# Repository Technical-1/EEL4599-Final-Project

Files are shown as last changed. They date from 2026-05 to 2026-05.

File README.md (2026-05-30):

# EEL4599 Final Project — Wireless Sensor Network

A multi-node wireless sensor network built around XBee/802.15.4 radios. Battery-powered sensor nodes measure temperature and light, transmit readings over the air as binary XBee API frames, and a WiFi-connected coordinator forwards those readings to the cloud (ThingSpeak) for logging and display.

This was a two-person final project for EEL4599. My focus was the **base-station coordinator** — the WiFi/cloud side that receives radio data and pushes it to ThingSpeak — alongside the shared XBee API frame work.

## System at a glance

```
[Temp Node]  --\
                 >--(XBee 802.15.4 RF)-->  [Coordinator] --(WiFi/HTTP)--> [ThingSpeak cloud]
[Light Node] --/                            + OLED status
```

## Features

- **Portable XBee API protocol layer** — a single C header (`xbee_api.h`) builds and parses XBee API frames (AT commands, transmit requests, receive packets) with checksum generation/verification, reused unchanged across Raspberry Pi Pico and Arduino targets.
- **Temperature node** — Raspberry Pi Pico reads a thermistor via the 12-bit ADC, converts resistance to temperature with the B-parameter (Steinhart–Hart) equation, and oversamples across a fixed interval to reduce noise before transmitting.
- **Light node** — Arduino-based node that reads a luminosity sensor and transmits lux readings over the same XBee frame format.
- **WiFi coordinator** — receives XBee data over UART and uploads it to ThingSpeak over HTTP; an SSD1306 OLED shows connection status and the assigned IP.
- **Host-side tools** — small Python and C utilities for sniffing and decoding XBee API frames during bring-up and debugging.

## Tech Stack

- **Languages**: C (embedded), CircuitPython / MicroPython, Arduino C++, Python (host tools)
- **Microcontrollers**: Raspberry Pi Pico (RP2040), Arduino, ESP8266, Adafruit Feather + ESP32 (AirLift) co-processor
- **Radio**: Digi XBee (802.15.4 / Zigbee) in API mode
- **Cloud**: ThingSpeak (HTTP REST ingest)
- **Build**: Pico SDK (CMake) for the Pico targets; Arduino IDE for the Arduino/ESP targets
- **Hardware design**: KiCad schematics for each node

## Project Structure

Each network component lives in its own directory:

```
EEL4599-Final-Project/
├── BaseStation/        # ESP8266 base station: WiFi connect + OLED status
├── FeatherWingFiles/   # CircuitPython coordinator that forwards XBee data to ThingSpeak
├── TempNode/           # Pico thermistor node (C, Pico SDK)
├── LightNode/          # Arduino luminosity node
├── XBeeAPI/            # XBee API frame library (xbee_api.h) + reference firmware
├── SerialReader/       # Host-side C tool that decodes XBee frames from a serial port
├── Diagrams/           # KiCad schematics and the data-flow diagram
├── ReceiveData.py      # Host-side digi-xbee receive tool
└── .portfolio/         # Project documentation
```

The three sensor/reference firmwares share one protocol implementation: `TempNode/xbee_api.h` and `LightNode/xbee_api.h` are **symlinks** to `XBeeAPI/xbee_api.h`, so there is a single source of truth for the frame format.

## Getting Started

### Prerequisites

- A pair (or more) of Digi XBee radios configured in **API mode**, one as coordinator
- Target boards: Raspberry Pi Pico and/or Arduino-class board for sensor nodes; an ESP8266/Feather for the coordinator
- [Pico SDK](https://github.com/raspberrypi/pico-sdk) + CMake (Pico targets) and/or the Arduino IDE
- Python 3 with the `digi-xbee` library for the host receive tool

### Build a Pico sensor node

```bash
# from the TempNode/ (or XBeeAPI/) directory
mkdir build && cd build
cmake ..
make
# flash the resulting .uf2 to the Pico
```

### Flash an Arduino node / coordinator

Open `LightNode/LightNode.ino` or `BaseStation/BaseStation.ino` in the Arduino IDE and upload to the board.

For the ESP8266 base station, create `BaseStation/WiFiCredentials.h` (git-ignored):

```c
const char* ssid = "your-ssid";
const char* pwd  = "your-password";
```

### Run the host receive tool

```bash
pip install digi-xbee
python ReceiveData.py   # edit PORT/BAUD_RATE to match your XBee
```

## License

Unlicensed (academic project).

## Authors

Jacob Kanfer — [GitHub](https://github.com/Technical-1) — and project partner. Two-person final project for EEL4599.

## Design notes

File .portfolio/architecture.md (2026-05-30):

# Architecture

## System Diagram

```mermaid
flowchart LR
    subgraph Sensor Nodes
        TN["Temp Node<br/>(RP2040 / Pico, C)<br/>thermistor + ADC"]
        LN["Light Node<br/>(Arduino)<br/>luminosity sensor"]
    end

    subgraph Shared
        API["xbee_api.h<br/>API-frame encode/decode<br/>+ checksum"]
    end

    TN -- includes --> API
    LN -- includes --> API

    TN -- "0x10 Transmit Request<br/>(2-byte payload)" --> RF(("XBee RF<br/>802.15.4"))
    LN -- "0x10 Transmit Request" --> RF

    RF -- "0x90 Receive Packet" --> CO["Coordinator<br/>(ESP8266 / Feather+ESP32)<br/>UART in"]
    CO -- "HTTP GET /update" --> TS["ThingSpeak<br/>cloud channel"]
    CO -- status --> OLED["SSD1306 OLED"]

    RF -. debug .-> HOST["Host tools<br/>ReceiveData.py /<br/>SerialReader.c"]
```

## Component Descriptions

### XBee API frame library
- **Purpose**: Encode and decode XBee API-mode frames so firmware never hand-assembles raw byte buffers.
- **Location**: `XBeeAPI/xbee_api.h` (symlinked from `TempNode/xbee_api.h` and `LightNode/xbee_api.h`, so all nodes share one copy)
- **Key responsibilities**: build AT command frames (`0x08`), transmit-request frames (`0x10`), and parse receive packets (`0x90`); compute and verify the XBee checksum; grow the frame buffer with `realloc` as needed. All UART I/O is delegated to two functions the host firmware must provide: `xbee_api_uart_write()` and `xbee_api_uart_getchar()`.

### Temperature node
- **Purpose**: Measure ambient temperature and broadcast it.
- **Location**: `TempNode/main.c`
- **Key responsibilities**: initialize UART + ADC on the Pico; oversample the thermistor across a fixed time window and average; convert ADC counts → resistance (voltage-divider) → temperature (B-parameter equation) → Fahrenheit; encode the reading as a fixed-point `int16` (°F × 10) and transmit it.

### Light node
- **Purpose**: Measure luminosity and broadcast it.
- **Location**: `LightNode/LightNode.ino`
- **Key responsibilities**: read the light sensor and transmit a 2-byte reading using the same XBee frame format, with the Arduino `Serial` port wired in as the API library's UART backend.

### Coordinator / base station
- **Purpose**: Receive sensor data over the air and forward it to the cloud.
- **Location**: `BaseStation/BaseStation.ino` (ESP8266 + OLED) and `FeatherWingFiles/code.py` (CircuitPython on Feather + ESP32 AirLift)
- **Key responsibilities**: connect to WiFi; read XBee frames over UART; issue an HTTP GET to the ThingSpeak `/update` endpoint with the reading in a field parameter; surface connection state and IP on the SSD1306 OLED.

### Host-side decoding tools
- **Purpose**: Bring-up and debugging without a microcontroller in the loop.
- **Location**: `ReceiveData.py` (digi-xbee library), `SerialReader/SerialReader.c` (raw serial parse), `XBeeAPI/xbee_api_receive.py`
- **Key responsibilities**: read frames from a serial port and print the decoded payload, so frame formatting and sensor math can be verified on a laptop.

## Data Flow

1. A sensor node samples its sensor (thermistor ADC, or light sensor).
2. The raw reading is converted to a physical value and packed into a 2-byte fixed-point payload.
3. The payload is wrapped in an XBee `0x10` transmit-request frame (with destination address and checksum) and written to the radio over UART.
4. The XBee mesh delivers the frame to the coordinator, which receives it as a `0x90` packet and extracts the payload.
5. The coordinator builds a ThingSpeak `/update` URL with the reading and issues an HTTP GET over WiFi; the OLED reflects status.

## External Integrations

| Service | Purpose | Notes |
|---|---|---|
| ThingSpeak  | Cloud logging / charting of data | HTTP GET to `/update` with an API key; one field per metric. |
| XBee radios | The RF transport itself | API mode (not transparent/AT mode) so payloads carry addressing + framing. |

## Key Architectural Decisions

### One protocol library, many MCUs
- **Context**: The temperature node (Pico, C/Pico SDK) and the light node (Arduino C++) run on different toolchains and have completely different UART APIs, but both must speak identical XBee frames.
- **Decision**: Put all framing logic in a header (`xbee_api.h`) that calls two externally-defined I/O functions, and let each firmware define those functions against its own UART.
- **Rationale**: Avoids forking the protocol code per board and guarantees the temp and light nodes can't drift into incompatible frame formats. The alternative — duplicating frame code in each `.ino`/`.c` — would have doubled the surface area for checksum/offset bugs.

### XBee API mode over transparent mode
- **Context**: Multiple sensor nodes report to one coordinator, which needs to know *who* sent each reading.
- **Decision**: Run the radios in API mode and parse `0x90` receive packets, which include the sender's 64-bit address, rather than transparent serial passthrough.
- **Rationale**: Transparent mode would have merged all nodes into one undifferentiated byte stream. API mode preserves per-node addressing and delivery status for free.

### Fixed-point payloads instead of strings
- **Context**: RF airtime and MCU memory are limited, and floats are awkward to transmit reliably.
- **Decision**: Encode each reading as a 2-byte `int16` scaled by 10 (e.g. 73.4 °F → `734`) and reconstruct on the receiver.
- **Rationale**: Keeps payloads to 2 bytes with predictable framing and no parsing ambiguity, versus sending variable-length ASCII like `"73.4F"`.

### Shared protocol library via symlinks
- **Context**: Three firmwares (the two Pico C targets and the Arduino node) each need the XBee frame code, but duplicating the header invites the copies to drift apart.
- **Decision**: Keep one real `XBeeAPI/xbee_api.h` and point `TempNode/xbee_api.h` and `LightNode/xbee_api.h` at it with symlinks, so each firmware still `#include "xbee_api.h"` locally but compiles the same bytes.
- **Rationale**: Guarantees one source of truth for the wire format across boards with different build systems (CMake vs Arduino IDE), without a build step to copy files around. The alternative — committing three independent copies — is exactly how the temp and light nodes briefly diverged during parallel development before being unified.

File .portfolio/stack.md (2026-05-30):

# Tech Stack

## Core Technologies

| Category | Technology | Why this choice |
|---|---|---|
| Sensor-node lang| C (Pico SDK) | Direct register/ADC/UART control on the RP2040 with predictable timing. |
| Sensor-node lang| Arduino C++ | Fast bring-up for the light node on Arduino-class hardware. |
| Coordinator lang| CircuitPython / MicroPython | High-level WiFi + HTTP on the Feather/ESP32 without a full native toolchain.|
| Coordinator lang| Arduino C++ (ESP8266 core) | OLED + WiFi on the ESP8266 base station. |
| RF transport | Digi XBee (802.15.4 / Zigbee) | API mode gives per-node addressing and delivery status. |
| Cloud | ThingSpeak | Free, HTTP-GET ingest and built-in charts — minimal coordinator code. |

## Sensor nodes

- **Temperature**: Raspberry Pi Pico (RP2040), thermistor on a voltage divider into the 12-bit ADC, B-parameter temperature model, oversampled and averaged in `TempNode/main.c`.
- **Light**: Arduino board reading a luminosity sensor, transmitting via `LightNode/LightNode.ino`.
- **Shared protocol**: `xbee_api.h` — hardware-agnostic XBee API frame encode/decode.

## Coordinator / base station

- **Boards**: ESP8266 (`BaseStation.ino`) and Adafruit Feather + ESP32 AirLift co-processor (`FeatherWingFiles/code.py`).
- **Display**: SSD1306 128×32 OLED over I²C (`Adafruit_SSD1306` + `Adafruit_GFX`).
- **Networking**: ESP8266 `WiFi`/`HTTPClient`, or `adafruit_esp32spi` + `adafruit_requests` on the Feather.

## Build & Tooling

- **Pico targets**: CMake + Pico SDK (`CMakeLists.txt`, `pico_sdk_import.cmake`), producing a `.uf2` to flash.
- **Arduino/ESP targets**: Arduino IDE / ESP8266 Arduino core.
- **Hardware design**: KiCad schematics for the base, temp, and light nodes (`Diagrams/schematic/`); data-flow diagram in draw.io.
- **Secrets**: WiFi credentials and the ThingSpeak API key are kept out of the repo (git-ignored `WiFiCredentials.h` / `secrets`).

## Key Dependencies

| Package | Purpose |
|---|---|
| `pico/stdlib`, `hardware/adc`, `hardware/uart` | RP2040 ADC sampling and UART transport. |
| `Adafruit_SSD1306`, `Adafruit_GFX` | Driving the OLED status display. |
| `ESP8266WiFi`, `ESP8266HTTPClient` | WiFi + HTTP on the base station. |
| `adafruit_esp32spi`, `adafruit_requests` | WiFi + HTTPS on the Feather coordinator. |
| `digi-xbee` (Python) | Host-side frame receive/decode during debugging. |

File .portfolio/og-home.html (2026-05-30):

EEL4599 // FINAL PROJECT

SSD1306 128x32

Connected to Wi-Fi

192.168.1.42

# Wireless Sensor Network

XBee radios → WiFi coordinator → the cloud

TempNode 73.4°F LightNode 500 lux ⟶ XBee 0x90 ⟶ ThingSpeak

7E 00 0E 10 01 00 00 00 00 00 00 00 00 FF FE 00 00 02 DE 7E 00 12 90 00 13 A2 00 41 .. .. .. C8 02 DE

XBee API mode RP2040 · Arduino · ESP Steinhart–Hart

github.com/Technical-1

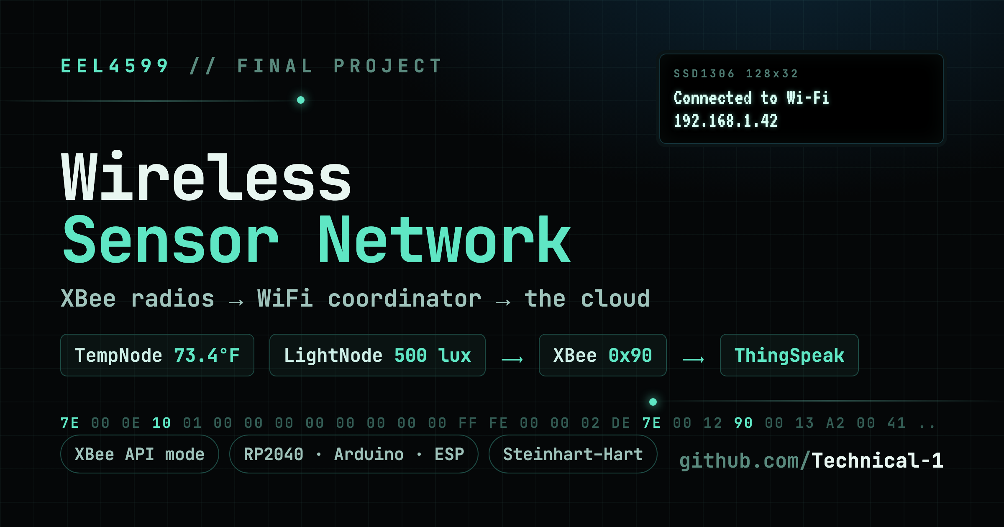
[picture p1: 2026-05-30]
.portfolio/preview.png

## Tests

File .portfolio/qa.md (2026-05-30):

# Project Q&A

## Overview

A wireless sensor network for EEL4599: small battery-powered nodes measure temperature and light, transmit their readings over XBee 802.15.4 radios as binary API frames, and a WiFi-connected coordinator forwards the data to ThingSpeak for logging and charting. The interesting engineering core is a single portable C header that speaks the full XBee API frame protocol and runs unchanged on two different microcontroller families.

## Problem Solved

Reading sensors in one place and viewing the data somewhere else means crossing two gaps: a wireless RF hop from the sensors to a hub, and an internet hop from the hub to the cloud. This project builds both halves — the RF link between sensor nodes and a coordinator, and the WiFi/HTTP link from the coordinator to ThingSpeak.

## Target Users

- **Students / makers** building multi-node sensor networks who want a worked XBee-API-mode example rather than transparent serial.
- **Anyone wiring a microcontroller to ThingSpeak** who needs a minimal coordinator that turns a UART reading into an HTTP update.

## Key Features

### Multi-node RF sensing
Independent temperature and light nodes each sample a sensor and transmit to a shared coordinator, with the radio's API mode preserving which node sent which reading.

### Portable XBee protocol layer
The framing/checksum logic lives in one header that both the Pico (C) and Arduino nodes include — they differ only in the two UART functions they supply.

### WiFi-to-cloud coordinator
The coordinator reads frames over UART, formats a ThingSpeak `/update` request, and posts it over WiFi, with an OLED showing connection status and IP.

## Technical Highlights

### Hardware-agnostic frame library via injected I/O
`xbee_api.h` implements AT (`0x08`), transmit-request (`0x10`), and receive (`0x90`) frame handling plus checksum compute/verify, but never touches a UART directly — it calls `xbee_api_uart_write()` and `xbee_api_uart_getchar()`, which each firmware defines. On the Pico those map to `uart_write_blocking`/`uart_getc`; on Arduino they map to `Serial.write`/`Serial.read`. One protocol implementation, two toolchains, zero duplication.

### Thermistor math with noise averaging
`TempNode/main.c` converts a 12-bit ADC reading to resistance through the voltage-divider equation, then to temperature with the B-parameter (Steinhart–Hart) model, and finally to Fahrenheit. Rather than transmit a single noisy sample, it accumulates many ADC reads across a fixed time window and averages them before each transmission, trading a little latency for a much steadier reading.

### Compact fixed-point wire format
Each reading is sent as a 2-byte `int16` scaled by 10 (73.4 °F travels as `734`, MSB first) and reconstructed on the receiver. This keeps every payload to exactly two bytes with no string parsing — the receiver code (`SerialReader.c`, `xbee_api_receive.py`) just shifts two bytes back together and divides by 10.

### Defensive frame parsing
The receive path reads the length bytes first and grows its buffer with `realloc` before reading the body, and re-verifies the checksum after assembly. The code comments even flag that trusting attacker-controlled length bytes is a risk — an honest acknowledgement of the parser's threat surface.

## Engineering Decisions

### API mode vs transparent mode
- **Constraint**: One coordinator must distinguish readings from multiple nodes.
- **Options**: Transparent (AT) mode passthrough, or API mode with structured frames.
- **Choice**: API mode.
- **Why**: API receive packets carry the sender's 64-bit address and a delivery status; transparent mode would have flattened all nodes into one indistinguishable byte stream.

### Header-with-callbacks vs per-board protocol copies
- **Constraint**: Two MCU families with incompatible UART APIs must emit identical frames.
- **Options**: Duplicate framing code in each firmware, or isolate it behind an I/O seam.
- **Choice**: Single header with two externally-defined I/O functions.
- **Why**: Eliminates the chance of the temp and light nodes drifting into incompatible frame layouts, and keeps checksum/offset logic in exactly one place.

### ThingSpeak vs a custom backend
- **Constraint**: The coordinator should publish readings with as little code as possible.
- **Options**: Stand up a custom HTTP server/database, or use a hosted IoT data sink.
- **Why**: ThingSpeak ingests data with a single authenticated HTTP GET and charts it out of the box, so the coordinator firmware stays tiny.

## Frequently Asked Questions

### How does a sensor reading get from a node to the cloud?
The node samples its sensor, packs the value into a 2-byte payload, wraps it in an XBee `0x10` transmit frame, and sends it over the radio. The coordinator receives it as a `0x90` packet, extracts the 2 bytes, and issues an HTTP GET to ThingSpeak's `/update` endpoint with the value in a field parameter.

### Why does each node folder have its own `xbee_api.h`?
There's actually only one real file — `TempNode/xbee_api.h` and `LightNode/xbee_api.h` are symlinks to `XBeeAPI/xbee_api.h`. That lets each firmware `#include "xbee_api.h"` locally and pair it with its own `xbee_api_uart_write`/`xbee_api_uart_getchar` implementation, while keeping a single source of truth for the frame format. The header has no platform dependencies of its own — the including file supplies the UART backend before the `#include`.

### How is the temperature actually computed?
ADC counts → resistance via the voltage divider, then resistance → temperature via the B-parameter equation (B = 3435, R₀ = 10 kΩ at 25 °C), converted to Fahrenheit. Readings are oversampled and averaged over a fixed interval before transmission.

### Why send `734` instead of `73.4`?
Fixed-point integers are smaller and unambiguous on the wire. The receiver divides by 10 to recover the decimal value, avoiding floating-point transmission and variable-length strings.

### How is the repository organized?
One directory per network component — `BaseStation/`, `FeatherWingFiles/` (coordinator), `TempNode/`, `LightNode/`, `XBeeAPI/`, `SerialReader/`, and `Diagrams/`. The firmwares use different build systems (Pico SDK/CMake vs Arduino IDE), so each keeps its own build config alongside its source.

### Where do WiFi credentials and the API key live?
Out of the repo. The base station includes a git-ignored `WiFiCredentials.h`, and the CircuitPython coordinator reads from a `secrets` module — neither is committed.

### Can I add a third sensor type?
Yes — write a node that includes `xbee_api.h`, defines the two UART functions for its board, samples its sensor, and calls `xbee_api_transmit_data()` with a 2-byte payload. The coordinator only needs a new ThingSpeak field to chart it.

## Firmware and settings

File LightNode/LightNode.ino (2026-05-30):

void xbee_api_uart_write(uint8_t* data, uint16_t len) {
  for(int i = 0; i < len; i++) {
    Serial.write(data[i]);
  }
}

uint8_t xbee_api_uart_getchar() {
  int value;
  while((value = Serial.read()) == -1);

  return (uint8_t)value;
}

#include "xbee_api.h"


void setup() {
  Serial.begin(9600, SERIAL_8N1);
}

void loop() {
    uint16_t number = 2024;
    char data[2];
    data[0] = 0xFF & (number >> 8);
    data[1] = 0xFF & (number >> 0);
    xbee_api_transmit_data(data, 2, 0x00000000);
    delay(1000);

}

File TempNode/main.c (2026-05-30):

#include <stdio.h>
#include "pico/stdlib.h"

#include "hardware/uart.h"
#include "hardware/adc.h"
#include <math.h>

#define UART uart0
#define BAUD_RATE 9600
#define DATA_BITS 8
#define STOP_BITS 1
#define PARITY UART_PARITY_NONE

#define UART_TX_PIN 0
#define UART_RX_PIN 1

void xbee_api_uart_write(uint8_t* data, uint16_t len) {
	uart_write_blocking(UART, data, len);
}

uint8_t xbee_api_uart_getchar() {
	return (uint8_t)uart_getc(UART);
}

#include "xbee_api.h"

// Compute the resistance using the voltage divider equation,
// recall that ADC is 12-bit and using 10k resistor in divider
float compute_resistance(float adc_value) {
	return 7.3e3 * (( (1 << 12) / adc_value ) - 1);
}

// Compute the temperature, in Fahrenheit
float compute_temperature(float R) {
	static const float B = 3435;
	static const float T0 = 25 + 273.15; // In Kelvin
	static const float R0 = 10e3;

	const float temp_K = 1 / (1 / T0 + 1/B * log(R / R0));
	const float temp_C = temp_K - 273.15;
	return (9 * temp_C) / 5 + 32;
}

int main() {
	stdio_init_all();

	uart_init(UART, BAUD_RATE);

	gpio_set_function(UART_TX_PIN, GPIO_FUNC_UART);
	gpio_set_function(UART_RX_PIN, GPIO_FUNC_UART);

	// Disable flow control
	uart_set_hw_flow(UART, false, false);

	// Set the uart format
	uart_set_format(UART, DATA_BITS, STOP_BITS, PARITY);

	// Enable the FIFO
	uart_set_fifo_enabled(UART, true);

	// Enable the ADC
	adc_init();
	adc_gpio_init(25);
	adc_select_input(0);
	volatile uint64_t start = time_us_64();
	volatile uint64_t end, diff;

	gpio_set_pulls(25, false, false);

	while(true) {
		//xbee_api_get_name();

		uint64_t total = 0;
		uint32_t count = 0;

		// Average all samples over the one-second interval
		do {
			total += adc_read();
			count++;
			end = time_us_64();
			diff = end - start;
		} while(diff < (uint64_t)40000000);
		start = end; //Update the start time for the next iteration

		float average = ((float) total) / count;

		float temp_F = compute_temperature(compute_resistance(average));

		printf("The temperature is %.02fF\n", temp_F);
		int16_t number = (int16_t)(temp_F * 10);

		char data[2];
		data[0] = 0xFF & (number >> 8);
		data[1] = 0xFF & (number >> 0);
		xbee_api_transmit_data(data, 2, 0x00000000);

		//tight_loop_contents();
	}
}

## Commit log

2024-04-14 Began UART-based API mode driver for XBee3 Module
2024-04-15 finished wifi connection and submission of data to thingverse as the coordinator. Finished reading zigbee data over uart. Need to test uart data receive with groups zigbee.
2024-04-25 Added packet reception to API, rewrote packet reception in CircuitPython
2024-04-25 Initial code for Light sensor
2024-04-26 Created schematics of all three nodes
    [BaseNode.kicad_sch, LightNode.kicad_sch, TempNode.kicad_sch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]
2024-04-26 Created Data Flow Diagram
2024-04-28 Compute and send temperature in Fahrenheit
2024-04-28 Fixed bug sample averaging code
    [main.c]
2026-05-30 assets: add spacing between flow row and hex strip in preview
